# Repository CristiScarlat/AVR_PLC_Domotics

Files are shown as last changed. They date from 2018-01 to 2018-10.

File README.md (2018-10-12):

This is a programmable PLC for home automations build around ATmega32, 
the electronic schematic can be found in the HW folder and the firmware in the AP_FW.
The firmware was writen in C using Atmel_Studio.
This PLC is programmable using an interface made in Java, the java project can be found in AP_SW directory

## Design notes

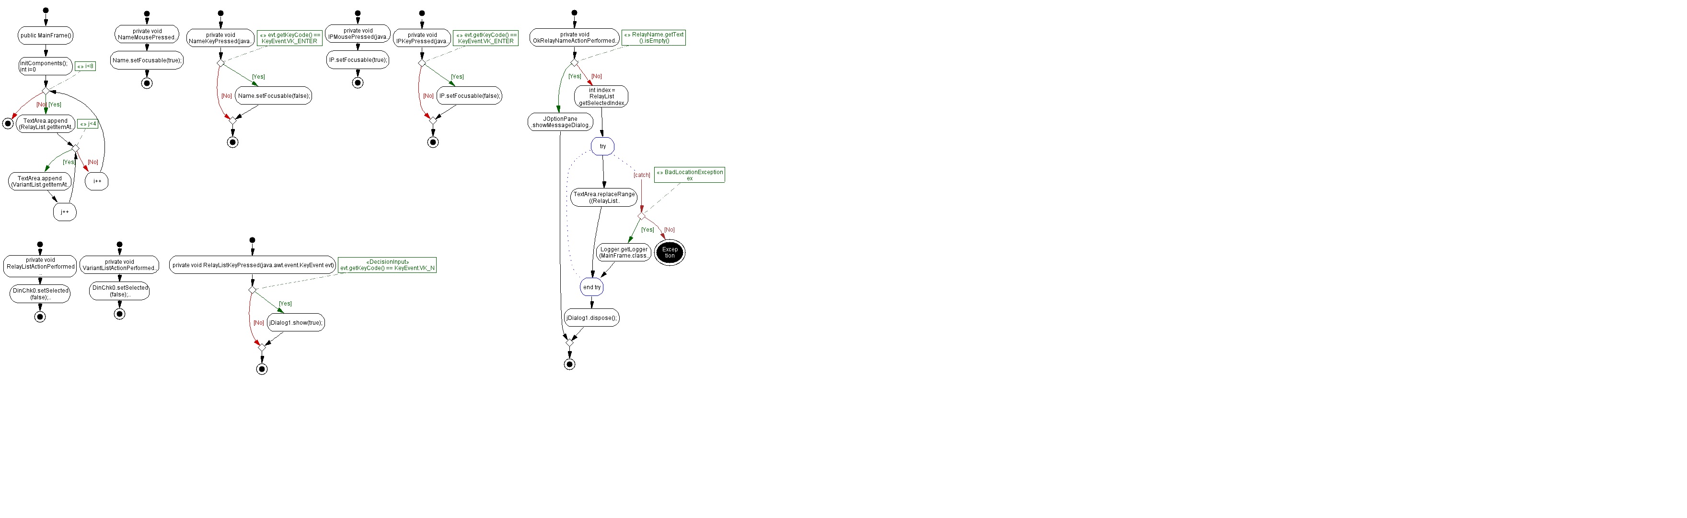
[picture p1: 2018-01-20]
AP_SW/UMLdiagrams.jpg

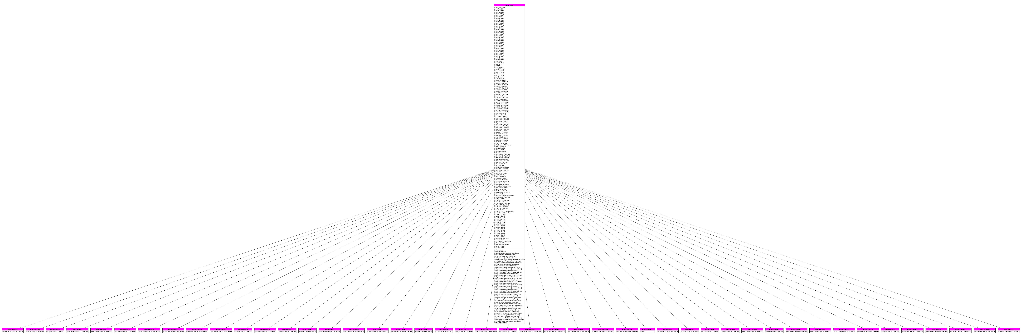
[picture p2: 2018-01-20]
AP_SW/UML.png

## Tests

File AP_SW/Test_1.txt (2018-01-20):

test/192.168.0.50/Digital IN 0/Digital IN 1/Digital IN 2/Digital IN 3/Digital IN 4/Digital IN 5/Digital IN 6/Digital IN 7/Analog IN 1 /Analog IN 2/Analog IN 3/Analog IN 4/Digital OUT 0/Digital OUT 1/Digital OUT 2/Digital OUT 3/Digital OUT 4/Digital OUT 5/Digital OUT 6/Digital OUT 7/r0d0v0r1d0v0r2a1214-408-v0r3a2408-622-v0r4a3615-816-v0r5a4816-1023-v0r6c13-13-08-10-v0r7l298-790-v0
Digital OUT 0:
Varianta 1:Digital IN 0->|
Varianta 2:-
Varianta 3:-
Varianta 4:-
Digital OUT 1:
Varianta 1:Digital IN 0->|
Varianta 2:-
Varianta 3:-
Varianta 4:-
Digital OUT 2:
Varianta 1:Analog IN 1 : ON = 1.0V<->2.0V->|
Varianta 2:-
Varianta 3:-
Varianta 4:-
Digital OUT 3:
Varianta 1:Analog IN 2: ON = 2.0V<->3.0V->|
Varianta 2:-
Varianta 3:-
Varianta 4:-
Digital OUT 4:
Varianta 1:Analog IN 3: ON = 3.0V<->4.0V->|
Varianta 2:-
Varianta 3:-
Varianta 4:-
Digital OUT 5:
Varianta 1:Analog IN 4: ON = 4.0V<->5.0V->|
Varianta 2:-
Varianta 3:-
Varianta 4:-
Digital OUT 6:
Varianta 1:Ceas: ON = 13:08 OFF = 13:10->|
Varianta 2:-
Varianta 3:-
Varianta 4:-
Digital OUT 7:
Varianta 1:Lumina: ON = 298 OFF = 790->|
Varianta 2:-
Varianta 3:-
Varianta 4:-

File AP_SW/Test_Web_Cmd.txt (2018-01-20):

Test_Web_Cmd/192.168.0.50/Digital IN 0/Digital IN 1/Digital IN 2/Digital IN 3/Digital IN 4/Digital IN 5/Digital IN 6/Digital IN 7/Analog IN 1/Analog IN 2/Analog IN 3/Analog IN 4/Digital OUT 0/Digital OUT 1/Digital OUT 2/Digital OUT 3/Digital OUT 4/Digital OUT 5/Digital OUT 6/Digital OUT 7/
Digital OUT 0:
Varianta 1:-
Varianta 2:-
Varianta 3:-
Varianta 4:-
Digital OUT 1:
Varianta 1:-
Varianta 2:-
Varianta 3:-
Varianta 4:-
Digital OUT 2:
Varianta 1:-
Varianta 2:-
Varianta 3:-
Varianta 4:-
Digital OUT 3:
Varianta 1:-
Varianta 2:-
Varianta 3:-
Varianta 4:-
Digital OUT 4:
Varianta 1:-
Varianta 2:-
Varianta 3:-
Varianta 4:-
Digital OUT 5:
Varianta 1:-
Varianta 2:-
Varianta 3:-
Varianta 4:-
Digital OUT 6:
Varianta 1:-
Varianta 2:-
Varianta 3:-
Varianta 4:-
Digital OUT 7:
Varianta 1:-
Varianta 2:-
Varianta 3:-
Varianta 4:-

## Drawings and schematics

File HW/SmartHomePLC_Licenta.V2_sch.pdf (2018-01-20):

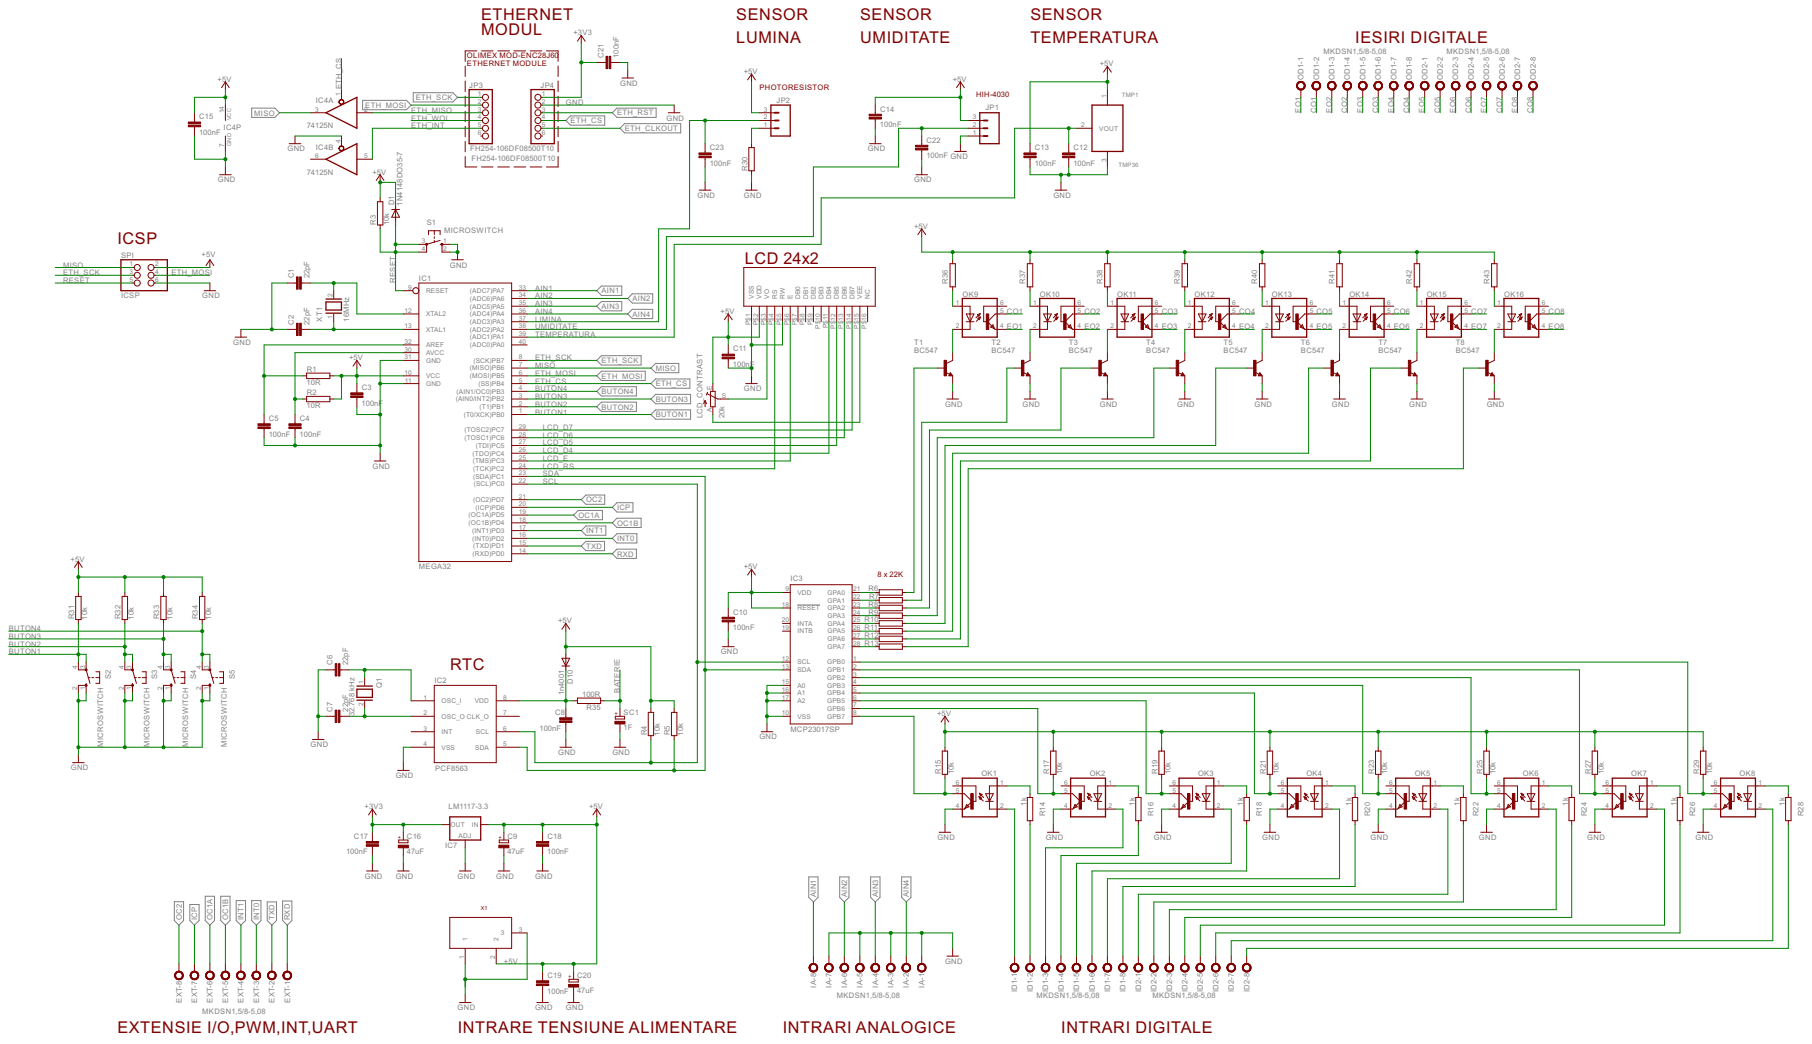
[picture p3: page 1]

PHOTORESISTOR OLIMEX MOD-ENC28J60 ETHERNET MODULE

28 LCD_D6
27 LCD_D5
26 LCD_D4
25 LCD_E

20 OC2 | ICP

MICROSWITCH MICROSWITCH

EXT-1 EXT-2 EXT-3 EXT-4 EXT-5 EXT-6 EXT-7 EXT-8

EXTENSIE I/O,PWM,INT,UART

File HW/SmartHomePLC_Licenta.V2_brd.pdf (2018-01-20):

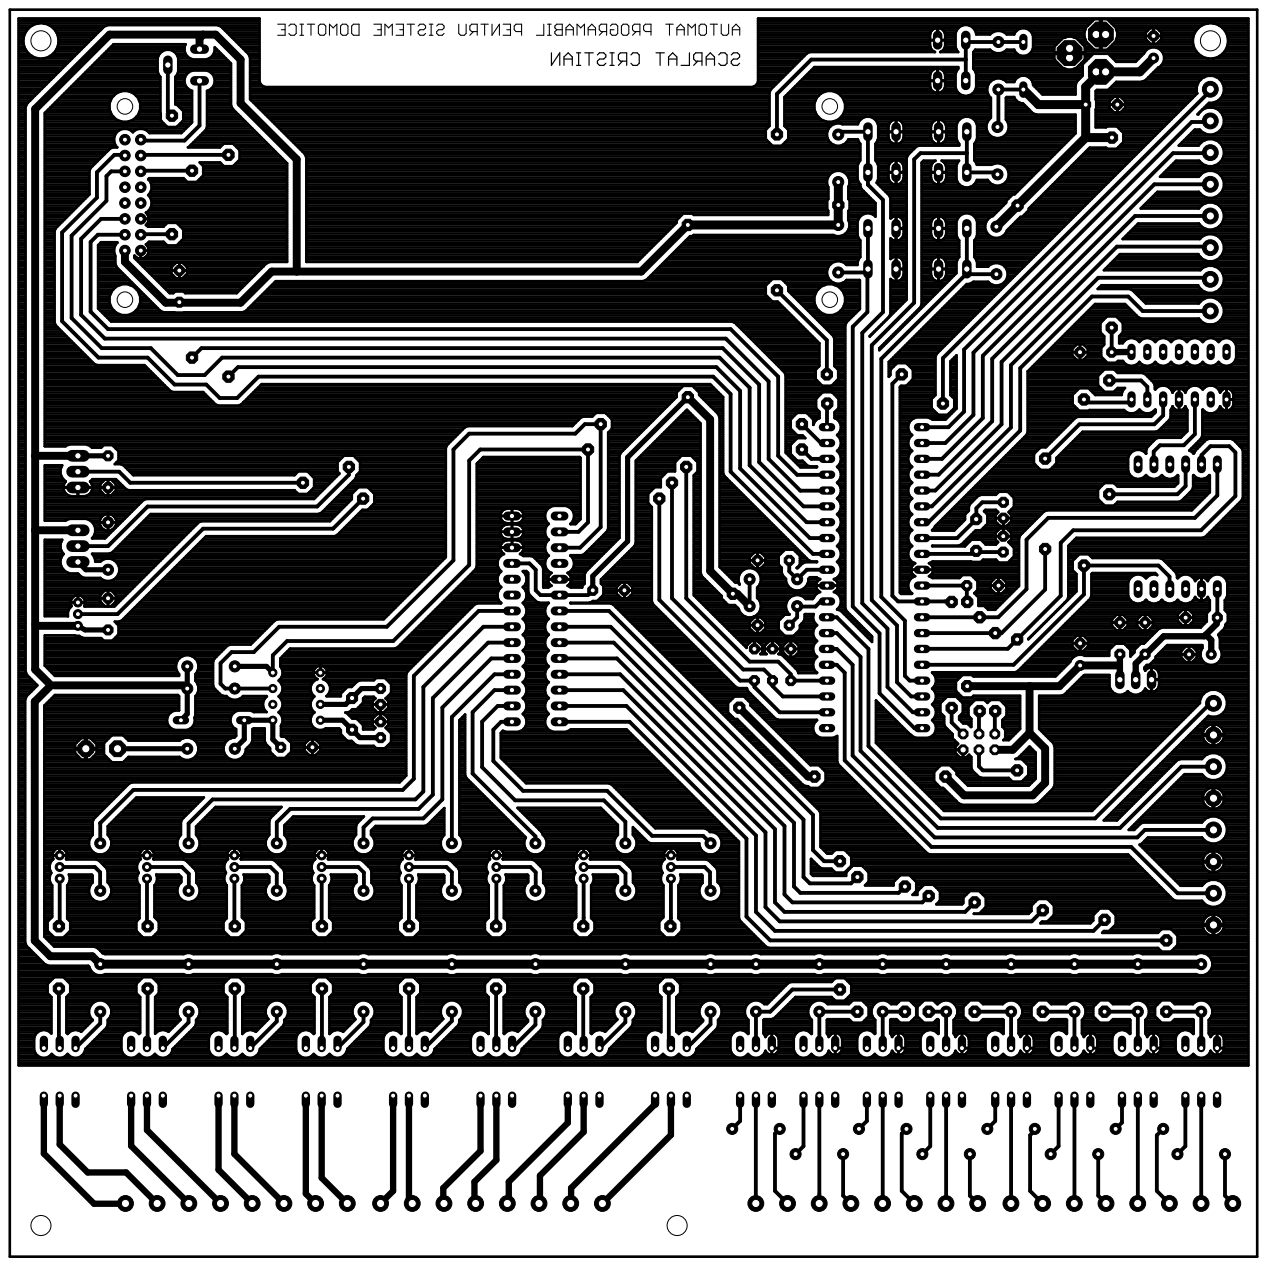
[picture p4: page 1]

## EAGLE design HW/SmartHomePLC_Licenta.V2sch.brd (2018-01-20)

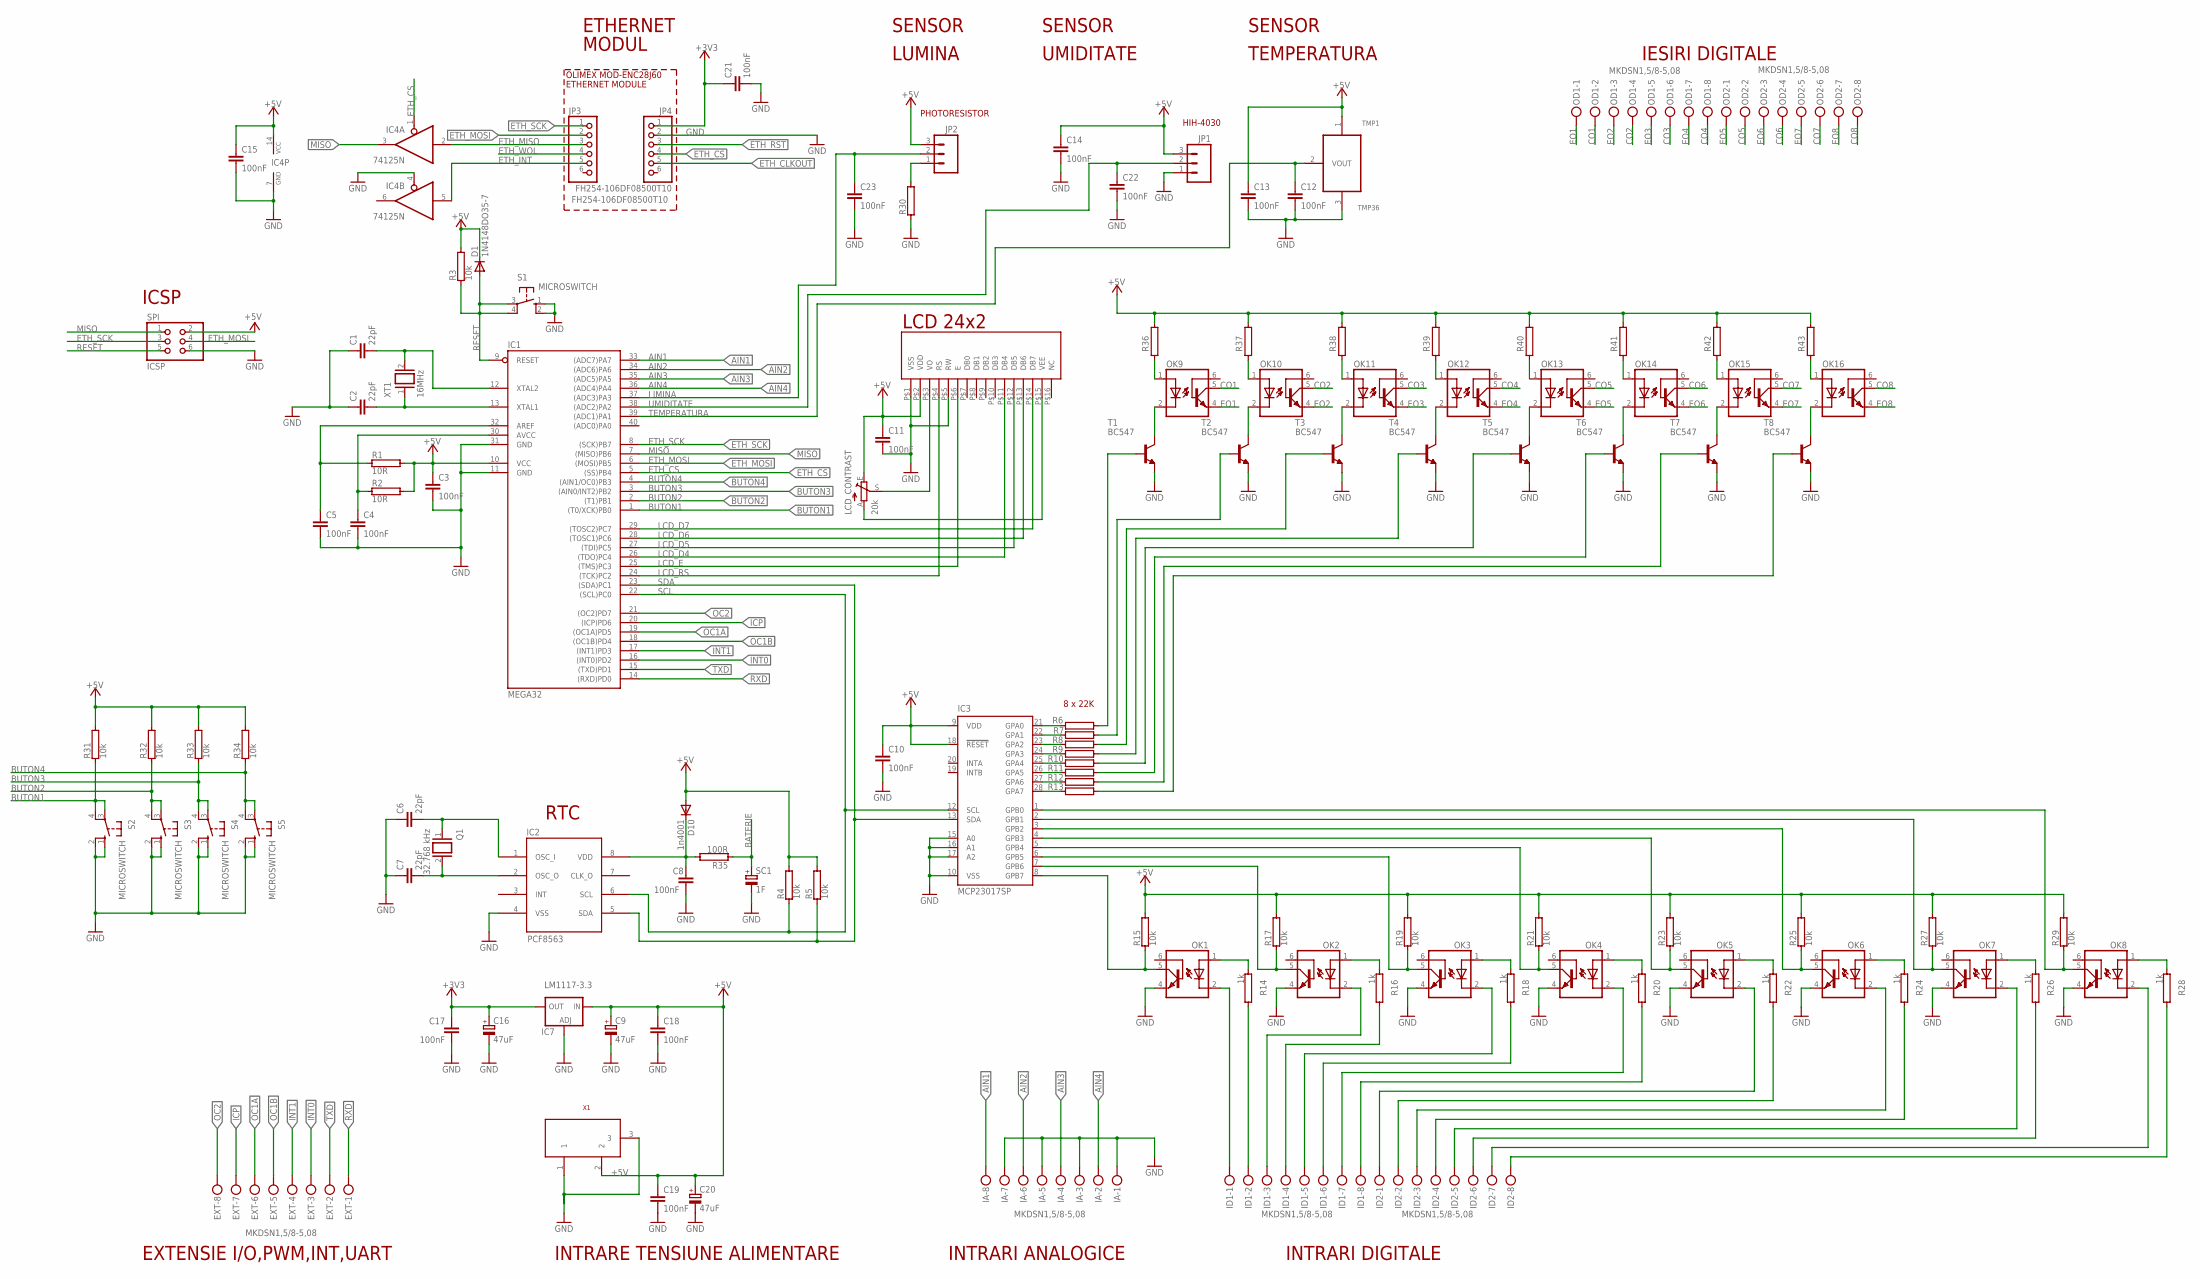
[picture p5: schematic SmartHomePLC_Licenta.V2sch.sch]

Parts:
C1, C2, C6, C7: 22pF; C2.5-2
C3, C4, C5, C8, C10, C11, C12, C13, C14, C15, C17, C18, C19, C21, C22, C23: 100nF; C5B2.5
C9, C16, C20: 47uF; E3,5-8
D1: 1N4148DO35-7; DO35-7
D10: 1n4001; DO35-10
EXT: MKDSN1,5/8-5,08
IA: MKDSN1,5/8-5,08
IC1: MEGA32; DIL40
IC2: PCF8563P; DIL08
IC3: MCP23017SP; DIL28-3
IC4: 74125N; DIL14
IC7: LM1117-3.3; 317TS
ID1, ID2: MKDSN1,5/8-5,08
JP1, JP2: M03LONGPADS; 1X03_LONGPADS
JP3, JP4: FH254-106DF08500T10; 1X06
LCD_CONTRAST: 20k; CA6V
OD1, OD2: MKDSN1,5/8-5,08
OK1, OK2, OK3, OK4, OK5, OK6, OK7, OK8, OK9, OK10, OK11, OK12, OK13, OK14, OK15, OK16: 4N35; DIL06
Q1: 32.768 kHz; QS
R1, R2: 10R; RS1/8
R3, R4, R5, R15, R17, R19, R21, R23, R25, R27, R29, R31, R32, R33, R34: 10k; RS1/8
R6, R7, R8, R9, R10, R11, R12, R13, R30, R36, R37, R38, R39, R40, R41, R42, R43: REZISTORSRS1/8; RS1/8
R14, R16, R18, R20, R22, R24, R26, R28: 1k; RS1/8
R35: 100R; RS1/8
S1, S2, S3, S4, S5: MICROSWITCH; B3F-10XX
SC1: 1F; DYNACAP-DB_1_3
SPI: ICSP; 2X03
T1, T2, T3, T4, T5, T6, T7, T8: BC547; BC-TO92
TMP1: TMP36; BC-TO92
U1: LCD_RC2402
X1: 0018_19746-POWER-SUPPLY; POWERSUPPLY_DC-21MM
XT1: 16MHz; QS

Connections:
+3V3: C16.+, C17.1, C21.1, IC7.2 (OUT), JP4.1
+5V: C3.1, C9.+, C10.1, C11.1, C13.1, C14.1, C15.1, C18.1, C19.1, C20.+, D1.C, D10.A, IC1.10 (VCC), IC3.9 (VDD), IC3.18 (!RESET), IC4.14 (VCC), IC7.3 (IN), JP1.3, JP2.3, LCD_CONTRAST.E, R1.2, R2.2, R3.2, R4.2, R5.2, R15.2, R17.2, R19.2, R21.2, R23.2, R25.2, R27.2, R29.2, R31.2, R32.2, R33.2, R34.2, R36.2, R37.2, R38.2, R39.2, R40.2, R41.2, R42.2, R43.2, SPI.2, TMP1.1 (+VS), U1.P$2 (VDD), X1.2
AIN1: IA.8, IC1.33 ((ADC7)PA7)
AIN2: IA.6, IC1.34 ((ADC6)PA6)
AIN3: IA.4, IC1.35 ((ADC5)PA5)
AIN4: IA.2, IC1.36 ((ADC4)PA4)
BATERIE: R35.1, SC1.+
BUTON1: IC1.1 ((T0/XCK)PB0), R31.1, S2.3, S2.4 (P1)
BUTON2: IC1.2 ((T1)PB1), R32.1, S3.3, S3.4 (P1)
BUTON3: IC1.3 ((AIN0/INT2)PB2), R33.1, S4.3, S4.4 (P1)
BUTON4: IC1.4 ((AIN1/OC0)PB3), R34.1, S5.3, S5.4 (P1)
CO1: OD1.2, OK9.5 (COL)
CO2: OD1.4, OK10.5 (COL)
CO3: OD1.6, OK11.5 (COL)
CO4: OD1.8, OK12.5 (COL)
CO5: OD2.2, OK13.5 (COL)
CO6: OD2.4, OK14.5 (COL)
CO7: OD2.6, OK15.5 (COL)
CO8: OD2.8, OK16.5 (COL)
EO1: OD1.1, OK9.4 (EMI)
EO2: OD1.3, OK10.4 (EMI)
EO3: OD1.5, OK11.4 (EMI)
EO4: OD1.7, OK12.4 (EMI)
EO5: OD2.1, OK13.4 (EMI)
EO6: OD2.3, OK14.4 (EMI)
EO7: OD2.5, OK15.4 (EMI)
EO8: OD2.7, OK16.4 (EMI)
ETH_CLKOUT: JP4.5
ETH_CS: IC1.5 ((SS)PB4), IC4.1 (OE), JP4.4
ETH_INT: IC4.5 (I), JP3.5
ETH_MISO: IC4.2 (I), JP3.3
ETH_MOSI: IC1.6 ((MOSI)PB5), JP3.2, SPI.4
ETH_RST: JP4.3
ETH_SCK: IC1.8 ((SCK)PB7), JP3.1, SPI.3
ETH_WOL: JP3.4
GND: C1.1, C2.1, C3.2, C4.2, C5.2, C6.1, C7.1, C8.2, C9.-, C10.2, C11.2, C12.2, C13.2, C14.2, C15.2, C16.-, C17.2, C18.2, C19.2, C20.-, C21.2, C22.2, C23.2, IA.1, IA.3, IA.5, IA.7, IC1.11 (GND), IC1.31 (GND), IC2.4 (VSS), IC3.10 (VSS), IC3.15 (A0), IC3.16 (A1), IC3.17 (A2), IC4.4 (OE), IC4.7 (GND), IC7.1 (ADJ), JP1.1, JP4.2, OK1.4 (EMI), OK2.4 (EMI), OK3.4 (EMI), OK4.4 (EMI), OK5.4 (EMI), OK6.4 (EMI), OK7.4 (EMI), OK8.4 (EMI), R30.1, S1.1 (S), S1.2 (S1), S2.1 (S), S2.2 (S1), S3.1 (S), S3.2 (S1), S4.1 (S), S4.2 (S1), S5.1 (S), S5.2 (S1), SC1.-, SPI.6, T1.1 (E), T2.1 (E), T3.1 (E), T4.1 (E), T5.1 (E), T6.1 (E), T7.1 (E), T8.1 (E), TMP1.3 (GND), U1.P$1 (VSS), U1.P$5 (RW), X1.1, X1.3
ICP: EXT.7, IC1.20 ((ICP)PD6)
INT0: EXT.3, IC1.16 ((INT0)PD2)
INT1: EXT.4, IC1.17 ((INT1)PD3)
LCD_D4: IC1.26 ((TDO)PC4), U1.P$11 (DB4)
LCD_D5: IC1.27 ((TDI)PC5), U1.P$12 (DB5)
LCD_D6: IC1.28 ((TOSC1)PC6), U1.P$13 (DB6)
LCD_D7: IC1.29 ((TOSC2)PC7), U1.P$14 (DB7)
LCD_E: IC1.25 ((TMS)PC3), U1.P$6 (E)
LCD_RS: IC1.24 ((TCK)PC2), U1.P$4 (RS)
LIMINA: C23.1, IC1.37 ((ADC3)PA3), JP2.2
MISO: IC1.7 ((MISO)PB6), IC4.3 (O), SPI.1
unnamed: C1.2, IC1.12 (XTAL2), XT1.2
unnamed: C2.2, IC1.13 (XTAL1), XT1.1
unnamed: C7.2, IC2.2 (OSC_O), Q1.2
unnamed: C4.1, IC1.30 (AVCC), R2.1
unnamed: C5.1, IC1.32 (AREF), R1.1
unnamed: IC3.28 (GPA7), R13.1
unnamed: IC3.27 (GPA6), R12.1
unnamed: IC3.26 (GPA5), R11.1
unnamed: IC3.25 (GPA4), R10.1
unnamed: IC3.24 (GPA3), R9.1
unnamed: C6.2, IC2.1 (OSC_I), Q1.1
unnamed: IC3.23 (GPA2), R8.1
unnamed: IC3.22 (GPA1), R7.1
unnamed: OK9.1 (A), R36.1
unnamed: IC3.21 (GPA0), R6.1
unnamed: OK9.2 (C), T1.3 (C)
unnamed: OK10.1 (A), R37.1
unnamed: R6.2, T1.2 (B)
unnamed: R7.2, T2.2 (B)
unnamed: OK11.1 (A), R38.1
unnamed: R8.2, T3.2 (B)
unnamed: R9.2, T4.2 (B)
unnamed: OK12.1 (A), R39.1
unnamed: OK13.1 (A), R40.1
unnamed: R10.2, T5.2 (B)
unnamed: LCD_CONTRAST.S, U1.P$3 (VO)
unnamed: LCD_CONTRAST.A, U1.P$15 (VEE)
unnamed: R11.2, T6.2 (B)
unnamed: OK14.1 (A), R41.1
unnamed: OK15.1 (A), R42.1
unnamed: R12.2, T7.2 (B)
unnamed: R13.2, T8.2 (B)
unnamed: OK1.1 (A), R14.1
unnamed: IC3.8 (GPB7), OK1.5 (COL), R15.1
unnamed: ID1.1, OK1.2 (C)
unnamed: OK16.1 (A), R43.1
unnamed: IC3.7 (GPB6), OK2.5 (COL), R17.1
unnamed: OK2.1 (A), R16.1
unnamed: ID1.3, OK2.2 (C)
unnamed: ID1.4, R16.2
unnamed: IC3.6 (GPB5), OK3.5 (COL), R19.1
unnamed: OK3.1 (A), R18.1
unnamed: ID1.5, OK3.2 (C)
unnamed: ID1.6, R18.2
unnamed: IC3.5 (GPB4), OK4.5 (COL), R21.1
unnamed: OK4.1 (A), R20.1
unnamed: ID1.7, OK4.2 (C)
unnamed: ID1.8, R20.2
unnamed: IC3.4 (GPB3), OK5.5 (COL), R23.1
unnamed: OK5.1 (A), R22.1
unnamed: ID2.1, OK5.2 (C)
unnamed: ID2.2, R22.2
unnamed: IC3.3 (GPB2), OK6.5 (COL), R25.1
unnamed: OK6.1 (A), R24.1
unnamed: ID2.3, OK6.2 (C)
unnamed: ID2.4, R24.2
unnamed: IC3.2 (GPB1), OK7.5 (COL), R27.1
unnamed: OK7.1 (A), R26.1
unnamed: OK10.2 (C), T2.3 (C)
unnamed: ID2.6, R26.2
unnamed: IC3.1 (GPB0), OK8.5 (COL), R29.1
unnamed: OK8.1 (A), R28.1
unnamed: ID2.7, OK8.2 (C)
unnamed: ID2.8, R28.2
unnamed: JP2.1, R30.2
unnamed: OK11.2 (C), T3.3 (C)
unnamed: OK12.2 (C), T4.3 (C)
unnamed: OK13.2 (C), T5.3 (C)
unnamed: OK14.2 (C), T6.3 (C)
unnamed: OK15.2 (C), T7.3 (C)
unnamed: OK16.2 (C), T8.3 (C)
unnamed: ID2.5, OK7.2 (C)
unnamed: C8.1, D10.C, IC2.8 (VDD), R35.2
unnamed: ID1.2, R14.2
OC1A: EXT.6, IC1.19 ((OC1A)PD5)
OC1B: EXT.5, IC1.18 ((OC1B)PD4)
OC2: EXT.8, IC1.21 ((OC2)PD7)
RESET: D1.A, IC1.9 (RESET), R3.1, S1.3, S1.4 (P1), SPI.5
RXD: EXT.1, IC1.14 ((RXD)PD0)
SCL: IC1.22 ((SCL)PC0), IC2.6 (SCL), IC3.12 (SCL), R4.1
SDA: IC1.23 ((SDA)PC1), IC2.5 (SDA), IC3.13 (SDA), R5.1
TEMPERATURA: C12.1, IC1.39 ((ADC1)PA1), TMP1.2 (VOUT)
TXD: EXT.2, IC1.15 ((TXD)PD1)
UMIDITATE: C22.1, IC1.38 ((ADC2)PA2), JP1.2

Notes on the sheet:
PHOTORESISTOR
OLIMEX MOD-ENC28J60
ETHERNET MODULE
INTRARI ANALOGICE
INTRARI DIGITALE
IESIRI DIGITALE
SENSOR
LUMINA
UMIDITATE
TEMPERATURA
ETHERNET
MODUL
RTC
ICSP
LCD 24x2
8 x 22K
INTRARE TENSIUNE ALIMENTARE
HIH-4030
EXTENSIE I/O,PWM,INT,UART

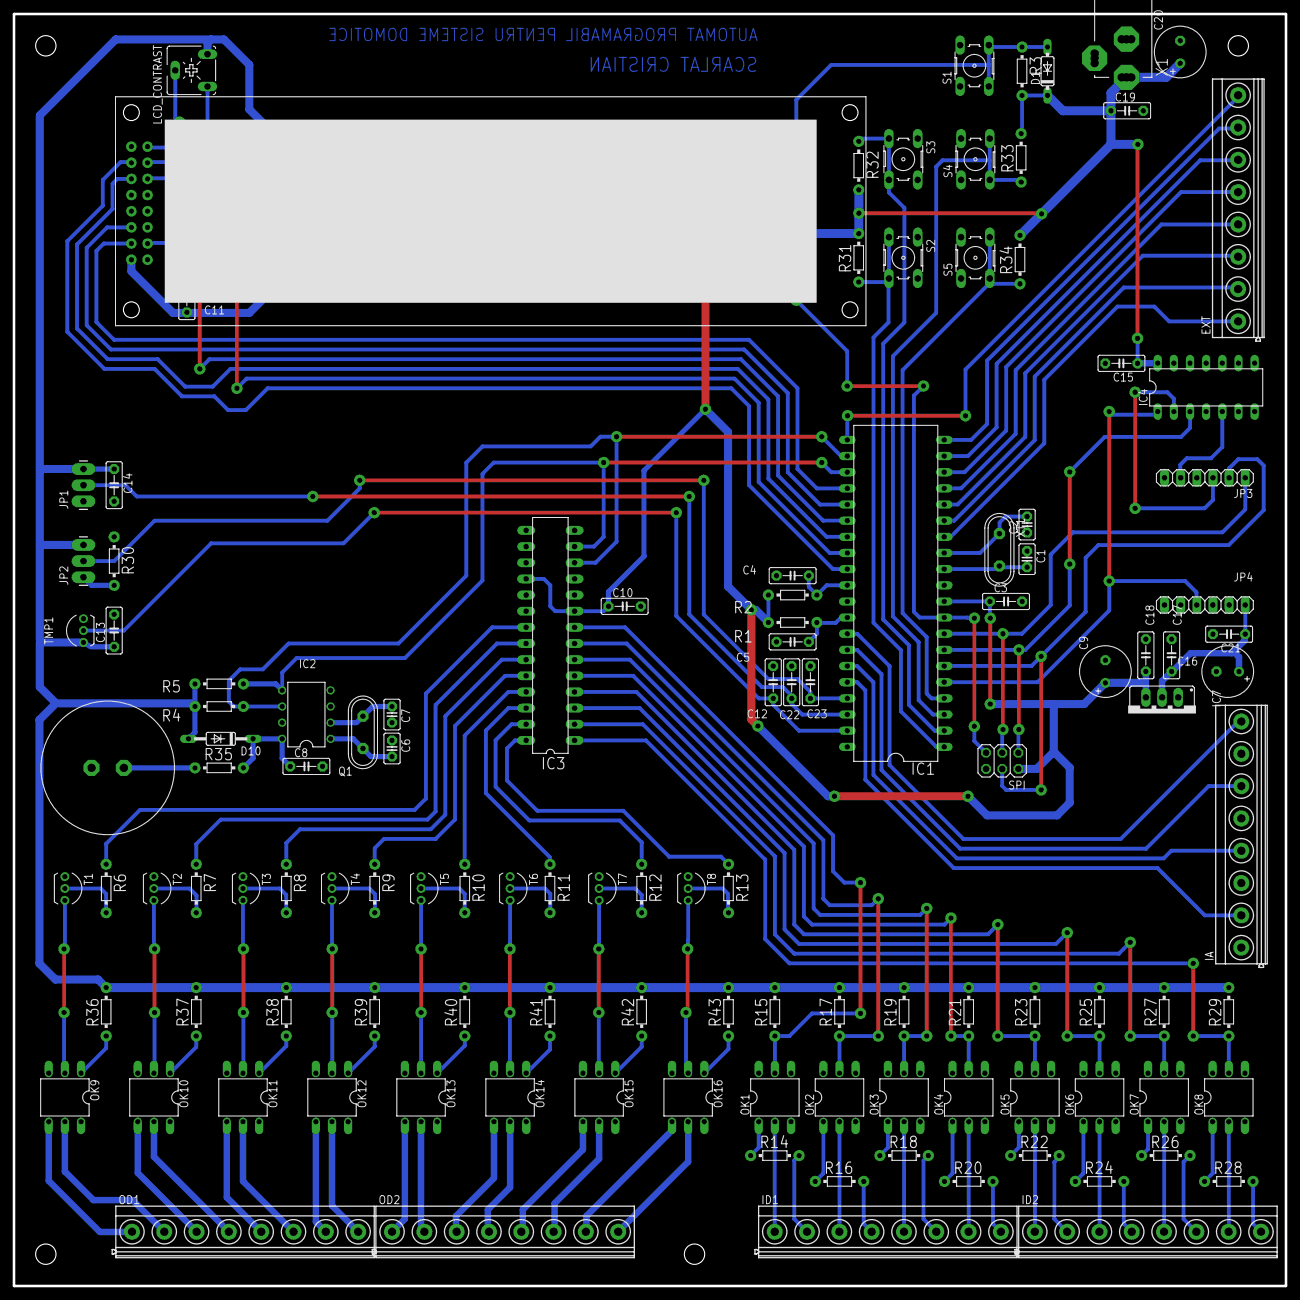
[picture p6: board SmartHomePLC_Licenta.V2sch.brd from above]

Board: 2 copper layers, 200.0 x 200.0 mm, 120 parts (0 on the bottom side), 128 nets.

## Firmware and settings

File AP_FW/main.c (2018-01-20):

/*
 * DomoticsPLC16.c
 *
 * Created: 9/30/2015 10:17:12 PM
 *  Author: Cristian Scarlat
 */ 
#define F_CPU 16000000UL

#include <stdio.h>
#include <stdlib.h>
#include <string.h>
#include <avr/io.h>
#include <avr/interrupt.h>
#include <avr/wdt.h>
#include <avr/eeprom.h>
#include <util/delay.h>

// ethernet interf
#include "ip_arp_udp.h"
//#include "ip_arp_udp.c"
#include "enc28j60.h"
//#include "enc28j60.c"
#include "net.h"
#include "timeout.h"
//#include "timeout.c"

#include "hd44780.h"
#include "hd44780_settings.h"
//#include "hd44780.c"

    char StrDisplay[10];
    char strRX[200];
	uint8_t DigIn = 0;//byte in care se citesc intrarile digitale de la MCP23017
	uint8_t ch = 0;// canal ADC
    float tempC;
	float hum;
	float light;
	uint8_t seconds;
	uint8_t minutes;
	uint8_t hours;
	uint8_t days;
	uint8_t weekdays = 0;
	uint8_t months;
	uint8_t years;
    uint8_t relays = 0x00;
	uint8_t menu = 0;
    uint8_t submenu = 0;
	//****************************************
	char Val[4];
	uint8_t relay=0;
	uint16_t valON=0;
	uint16_t valOFF =0;
	uint8_t Hon = 0;
	uint8_t Hoff = 0;
	uint8_t Mon = 0;
	uint8_t Moff = 0;
	uint8_t i=0;
	uint8_t j=0;
	uint8_t k=0;
	uint8_t eventsRX=0;//conditii gasite in strRX stringul receptionat de pe UDP
	uint8_t eventsTRUE = 0;// conditii TRUE , indeplinite pentru a comuta releul
	uint8_t OR = 0;
	uint8_t Validare[4];
	uint8_t flags;
	//***************************************
	
        // keep a track of number of overflows
        uint8_t refresh;
	
        uint16_t plen;
        uint8_t payloadlen=0;
	
// please modify the following two lines. mac and ip have to be unique
// in your local area network. You can not have the same numbers in
// two devices:
static uint8_t mymac[6] = {0x54,0x55,0x58,0x10,0x00,0x24};
static uint8_t myip[4] = {192,168,0,10};
static uint16_t myport =1200; // listen port for udp
// how did I get the mac addr? Translate the first 3 numbers into ascii is: TUX	
#define BUFFER_SIZE 250
static uint8_t buf[BUFFER_SIZE+1];
	

void TWI_Init()
{
	// 100kHz...SCL
	TWBR = 0x48;							//Set bitrate factor to 0
	TWSR &= ~((1<<TWPS1) | (1<<TWPS0));				//Set prescaler to 1
}

void TWI_Start()
{
	TWCR = (1<<TWINT) | (1<<TWEN) | (1<<TWSTA);
	while (!(TWCR & (1<<TWINT)));
}

void TWI_Stop()
{
	TWCR = (1<<TWINT) | (1<<TWEN) | (1<<TWSTO);
	while ((TWCR & (1<<TWSTO)));
}

uint8_t TWI_Read(uint8_t ack)
{
	TWCR = (1<<TWINT) | (1<<TWEN) | (((ack ? 1 : 0)<<TWEA));
	while (!(TWCR & (1<<TWINT)));
	return TWDR;
}


void TWI_Write(uint8_t byte)
{
	TWDR = byte;
	TWCR = (1<<TWINT) | (1<<TWEN);
	while (!(TWCR & (1<<TWINT)));
}
 

void init(void)
{
    DDRB &= ~((1 << 0)|(1 << 1)|(1 << 2)|(1 << 3));
////////////////////////Timer 0 and Interupt //////////////////////////////////////
   // set up timer with prescaler = 1024
    TCCR0 |= (1 << CS02)|(1 << CS00);
  //OCR set for 10ms
    OCR0 = 0x9B;
    // enable compare  interrupt
   TIMSK |= (1 << OCIE0);
    // enable global interrupts
    sei();
  
    // initialize overflow counter variable
    refresh = 0;
///////////////////////////////////////////////////////////////
	lcd_init();
	lcd_clrscr();
	lcd_puts("PLC FOR DOMOTICS");
	lcd_goto(0x40);
	lcd_puts("V1.0_10_2015");
	_delay_ms(1000);
	lcd_clrscr();
	lcd_puts("Author:");
	lcd_goto(0x40);
	lcd_puts("Cristian Scarlat");
	_delay_ms(1000);
        lcd_clrscr();
        _delay_ms(100);
	 TWI_Init();
         //PCF8563 Status and control registers write
	 TWI_Start();
         TWI_Write(0xA2);
	 TWI_Write(0x00);
	 TWI_Write(0x00);
         TWI_Stop();
         TWI_Start();
         TWI_Write(0xA2);
         TWI_Write(0x01);
	 TWI_Write(0x00);
	 TWI_Stop();
	 //MCP23017 init
         TWI_Start();
	 TWI_Write(0x40); //MCP23017 address A0=0,A1=0,A2=0 , Write mode
	 TWI_Write(0x00); //MCP23017 IODIRA register address
	 TWI_Write(0x00); //MCP23017 PORTA set to output
	 TWI_Stop();
	 TWI_Start();
	 TWI_Write(0x40); //MCP23017 address A0=0,A1=0,A2=0 , Write mode
	 TWI_Write(0x12); //MCP23017 GPIOA register address
	 TWI_Write(0x00); //MCP23017 reset port GPA
	 TWI_Stop();
	 TWI_Start();
	 TWI_Write(0x40); //MCP23017 address A0=0,A1=0,A2=0 , Write mode
	 TWI_Write(0x01); //MCP23017 IODIRB register address
	 TWI_Write(0xFF); //MCP23017 PORTB set to input
	 TWI_Stop();
	 //MCP23017 Read PortB*******************************************
	 TWI_Start();
	 TWI_Write(0x40); //MCP23017 address A0=0,A1=0,A2=0 , Write mode
	 TWI_Write(0x13); //MCP23017 GPIOB register address
	 TWI_Stop();
	 TWI_Start();
	 TWI_Write(0x41); //MCP23017 address A0=0,A1=0,A2=0 , Read mode
	 DigIn = TWI_Read(0);
	 TWI_Stop();
	 //***************************************************************
	 _delay_ms(100);
      //Analog inputs init
		//ADMUX = 1<<REFS0;
		ADMUX &= ~((1<<REFS0)|(1<<REFS1));//AREF,Internal Vreff turned off
		ADCSRA = (1<<ADEN)|(1<<ADPS2)|(1<<ADPS1)|(1<<ADPS0);
		//while(ADCSRA & (1<<ADSC));
        //*****************************************************************
	i=0;
	for(i=0;i<200;i++){
			strRX[i] = 0;
			}
	i=0;
	eeprom_read_block((char*)strRX,(void*)0,200);
	 /*initialize enc28j60*/
        enc28j60Init(mymac);
        delay_ms(20);

        
        /* Magjack leds configuration, see enc28j60 datasheet, page 11 */
        // LEDB=yellow LEDA=green
        //
        // 0x476 is PHLCON LEDA=links status, LEDB=receive/transmit
        // enc28j60PhyWrite(PHLCON,0b0000 0100 0111 01 10);
        enc28j60PhyWrite(PHLCON,0x476);
        delay_ms(20);

        //init the ethernet/ip layer:
        init_ip_arp_udp(mymac,myip);
}

void RelayToggle(uint8_t RelayNo)
{
	TWI_Start();
	TWI_Write(0x40); //MCP23017 address A0=0,A1=0,A2=0 , Write mode
	TWI_Write(0x12); //MCP23017 GPIOA register address
	relays ^= 1<<RelayNo;
	TWI_Write(relays); //MCP23017 set GPA0
	TWI_Stop();
}

void RelayON(uint8_t RelayNo)
{
	TWI_Start();
	TWI_Write(0x40); //MCP23017 address A0=0,A1=0,A2=0 , Write mode
	TWI_Write(0x12); //MCP23017 GPIOA register address
	relays |= (1<<RelayNo);
	TWI_Write(relays); //MCP23017 set GPA0
	TWI_Stop();
}

void RelayOFF(uint8_t RelayNo)
{
	TWI_Start();
	TWI_Write(0x40); //MCP23017 address A0=0,A1=0,A2=0 , Write mode
	TWI_Write(0x12); //MCP23017 GPIOA register address
	relays &= ~(1<<RelayNo);
	TWI_Write(relays); //MCP23017 set GPA0
	TWI_Stop();
}

void ReadDigIn(void)
{
	//MCP23017 Read PortB*******************************************
	 TWI_Start();
	 TWI_Write(0x40); //MCP23017 address A0=0,A1=0,A2=0 , Write mode
	 TWI_Write(0x13); //MCP23017 GPIOB register address
	 TWI_Stop();
	 TWI_Start();
	 TWI_Write(0x41); //MCP23017 address A0=0,A1=0,A2=0 , Read mode
	 DigIn = TWI_Read(0);
	 TWI_Stop();
	 //Revers order of bits******************************************
	 DigIn = (DigIn & 0xF0) >> 4 | (DigIn & 0x0F) << 4;
	 DigIn = (DigIn & 0xCC) >> 2 | (DigIn & 0x33) << 2;
	 DigIn = (DigIn & 0xAA) >> 1 | (DigIn & 0x55) << 1;
	 //***************************************************************
         DigIn = ~DigIn;//Operatie de NOT pentru ca iesirea optocuploarelor este cu colector in gol
}

void readtemp(void)
{               //set channel 1
	        ADMUX |= (1<<MUX0);
		ADMUX &= ~((1<<MUX1)|(1<<MUX2)|(1<<MUX3)|(1<<MUX4));
		// start single convertion
		// write ’1? to ADSC
		ADCSRA |= (1<<ADSC);
		// wait for conversion to complete
		// ADSC becomes ’0? again
		// till then, run loop continuously
		while(ADCSRA & (1<<ADSC));
		float Volt = (ADC*5)/1023.0;
		      tempC = (Volt-0.5)*100;
		dtostrf(tempC,5,1,StrDisplay);	
}

void readhum(void)
{        
          //set channel 2
	        ADMUX |= (1<<MUX1);
		ADMUX &= ~((1<<MUX0)|(1<<MUX2)|(1<<MUX3)|(1<<MUX4));
		// start single convertion
		// write ’1? to ADSC
		ADCSRA |= (1<<ADSC);
		// wait for conversion to complete
		// ADSC becomes ’0? again
		// till then, run loop continuously
		while(ADCSRA & (1<<ADSC));
		float Volt = (ADC*5.0)/1023.0;
		float  SensorRH = (Volt- 0.958) / 0.0307;
                 hum = SensorRH / (1.0546 - 0.00216 * tempC);
		dtostrf(hum,5,1,StrDisplay);	
}

uint16_t readlight()
{                //set channel 3
	        ADMUX |= (1<<MUX0)|(1<<MUX1);
		ADMUX &= ~((1<<MUX2)|(1<<MUX3)|(1<<MUX4));
		// start single convertion
		// write ’1? to ADSC
		ADCSRA |= (1<<ADSC);
		// wait for conversion to complete
		// ADSC becomes ’0? again
		// till then, run loop continuously
		while(ADCSRA & (1<<ADSC));
		light = ADC;
		return(light);
}
uint16_t readan (uint8_t ch)
{       ADMUX &= ~((1<<MUX0)|(1<<MUX1)|(1<<MUX2)|(1<<MUX3)|(1<<MUX4));
	switch(ch){
		case 1:
			ADMUX |= (1<<MUX0)|(1<<MUX1)|(1<<MUX2); 
			break;
		case 2:
			ADMUX |= (1<<MUX1)|(1<<MUX2); 
			break;
		case 3:
			ADMUX |= (1<<MUX0)|(1<<MUX2); 
			break;
		case 4:
			ADMUX |= 1<<MUX2; 
			break;
	}
	ADCSRA |= (1<<ADSC);
	while(ADCSRA & (1<<ADSC));
        uint16_t Val = ADC;
	return(Val);
}

// Converts a BCD (binary coded decimal) to decimal
uint8_t BcdToDec(uint8_t value)
{
  return ((value / 16) * 10 + value % 16);
}

// Converts a decimal to BCD (binary coded decimal)
uint8_t DecToBcd(uint8_t value){
  return ((value / 10) * 16 + value % 10);
}

void ReadRTC(void)
{
	 //Citire PCF8563 ********************************
	 TWI_Start();
	 TWI_Write(0xA2); //I2C Address pentru scriere
	 TWI_Write(0x02); //pointer la registru Seconds
	 TWI_Stop();
	 TWI_Start();
	 TWI_Write(0xA3); //I2C Address pentru citire *** adresele registrelor sunt incrementate automat (datasheet)
	 seconds = TWI_Read(1);//generate akc bit
	 minutes = TWI_Read(1);
	 hours = TWI_Read(1);
	 days = TWI_Read(1);
	 weekdays = TWI_Read(1);
	 months = TWI_Read(1);
	 years = TWI_Read(0); //do not generate akc bit
	 TWI_Stop();
	 //***********************************************
         seconds &= ~(1<<7);
         minutes &= ~(1<<7);
         hours &= ~((1<<7)|(1<<6));
         days &= ~((1<<7)|(1<<6));
         months &= ~((1<<7)|(1<<6)|(1<<5));
         seconds = BcdToDec(seconds);
         minutes = BcdToDec(minutes);
         hours = BcdToDec(hours);
         days = BcdToDec(days);
         months = BcdToDec(months);
         years = BcdToDec(years);
         
}
void WriteRTC(void)
{
 ////////////////convert Decimal values to BCD for PCF8563///////////////////
uint8_t setS = DecToBcd(seconds);
uint8_t setMin = DecToBcd(minutes);
uint8_t setH = DecToBcd(hours);
uint8_t setD = DecToBcd(days);
uint8_t setMon = DecToBcd(months);
uint8_t setY = DecToBcd(years);
////////////////////////////////////////////////////////////////////////////
	 TWI_Start();
	 TWI_Write(0xA2);//PCF8563 write I2C address
	 TWI_Write(0x02);// registru secunde, apoi valoarea registrilor este incrementata automat
	 TWI_Write(setS);
	 TWI_Write(setMin);
	 TWI_Write(setH);
	 TWI_Write(setD);
	 TWI_Write(weekdays);
	 TWI_Write(setMon);
	 TWI_Write(setY);
	 TWI_Stop();
}

void displayTime(){
                     lcd_clrscr();
            	     //lcd_goto(0);
                     if(hours < 10) lcd_puts("0");//afiseaza un "0" la zecimale daca ora<10
                     lcd_puts(itoa(hours,StrDisplay,10));// converteste integerul in sring si afiseaza pe LCD

                     lcd_puts(":");
                     if(minutes < 10)lcd_puts("0");
                     lcd_puts(itoa(minutes,StrDisplay,10));

                     //lcd_puts(":");
                     //if(seconds < 10)lcd_puts("0");
                     //lcd_puts(itoa(seconds,StrDisplay,10));

                     lcd_puts(" Date:");

                     if(days < 10)lcd_puts("0");
                     lcd_puts(itoa(days,StrDisplay,10));
                     lcd_puts("/");

                   //lcd_puts(itoa(weekdays,StrDisplay,10));
                   //StrDisplay[] = 0;
                   //lcd_puts("/");
                     if(months < 10)lcd_puts("0");	
                     lcd_puts(itoa(months,StrDisplay,10));

                     lcd_puts("/");
                     lcd_puts(itoa(years,StrDisplay,10));
}

void setTime(void){
        
        lcd_command(0x0E);//Cursor on blinking

 while(menu == 1){
        _delay_ms(100);
	displayTime();
	lcd_goto(0x40);//second line
	lcd_puts("IP:");
	lcd_goto(44);
	lcd_puts(itoa(myip[0],StrDisplay,10));
	lcd_puts(".");
	lcd_puts(itoa(myip[1],StrDisplay,10));
	lcd_puts(".");
	lcd_puts(itoa(myip[2],StrDisplay,10));
	lcd_puts(".");
	lcd_puts(itoa(myip[3],StrDisplay,10));
	lcd_goto(0);
	if(!(PINB & (1 << PINB1))){
		//init the ethernet/ip layer:
		init_ip_arp_udp(mymac,myip);
		lcd_command(0x0C);//Cursor off
		menu = 0;
		submenu = 0;
	}
	if(submenu == 0){
                 lcd_goto(0);
		if(!(PINB & (1 << PINB3))){
			_delay_ms(100);
			hours++;
			if(hours>23)hours=0;
		}
		if(!(PINB & (1 << PINB0))){
			_delay_ms(100);
			hours--;
			if(hours == 255)hours=23;
		}
		if(!(PINB & (1 << PINB2))){
                          while(!(PINB & (1 << PINB2)));
                         _delay_ms(100);
                        submenu++;				
                           }
	}
        if(submenu == 1){
                 lcd_goto(3);  
		if(!(PINB & (1 << PINB3))){
			_delay_ms(100);
			minutes++;
			if(minutes > 59)minutes=0;
		}
		if(!(PINB & (1 << PINB0))){
			_delay_ms(100);
			minutes--;
			if(minutes == 255)minutes=59;
		}
		if(!(PINB & (1 << PINB2))){
                          while(!(PINB & (1 << PINB2)));
                         _delay_ms(100);
                        submenu++;				
                           }
	}
        if(submenu == 2){
                 lcd_goto(11);
		if(!(PINB & (1 << PINB3))){
			_delay_ms(100);
			 days++;
			if(days > 31)days=0;				
		}
		if(!(PINB & (1 << PINB0))){
			_delay_ms(100);
			days--;
			if(days == 255)days=31;
		}
		if(!(PINB & (1 << PINB2))){
                          while(!(PINB & (1 << PINB2)));
                         _delay_ms(100);
                        submenu++;
                           }
	}
	if(submenu == 3){
                 lcd_goto(14);
		if(!(PINB & (1 << PINB3))){
			_delay_ms(100);
			 months++;
			if(months > 12)months=0;
		}
		if(!(PINB & (1 << PINB0))){
			_delay_ms(100);
			months--;
			if(months == 255)months=12;
		}
		if(!(PINB & (1 << PINB2))){
                          while(!(PINB & (1 << PINB2)));
                         _delay_ms(100);
                        submenu++;				
                           }
	}
	if(submenu == 4){
                 lcd_goto(17);
		if(!(PINB & (1 << PINB3))){
			_delay_ms(100);
			 years++;
			if(years > 99)years=0;
		}
		if(!(PINB & (1 << PINB0))){
			_delay_ms(100);
			years--;
			if(years == 255)years=99;
		}
		if(!(PINB & (1 << PINB2))){
                          while(!(PINB & (1 << PINB2)));
                         _delay_ms(100);
                        submenu++;				
                           }
	}
	if(submenu == 5){

			  //uint8_t myip[4] = {192,168,0,10};
				lcd_goto(45); 
				lcd_command(0x0E);//Cursor on blinking 		
			  if(!(PINB & (1 << PINB3))){
				  _delay_ms(100);
				  myip[0]++;

			  }
			  if(!(PINB & (1 << PINB0))){
				  _delay_ms(100);
				  myip[0]--;

			  }
			  if(!(PINB & (1 << PINB2))){
				  while(!(PINB & (1 << PINB2)));
				  _delay_ms(100);
				  submenu++;
			  }
	}
	if(submenu == 6){

			//uint8_t myip[4] = {192,168,0,10};
			lcd_goto(0x49);//second line

			if(!(PINB & (1 << PINB3))){
				_delay_ms(100);
				myip[1]++;

			}
			if(!(PINB & (1 << PINB0))){
				_delay_ms(100);
				myip[1]--;

			}
			if(!(PINB & (1 << PINB2))){
				while(!(PINB & (1 << PINB2)));
				_delay_ms(100);
				submenu++;
			}
		}
	if(submenu == 7){

				//uint8_t myip[4] = {192,168,0,10};
				lcd_goto(0x4C);//second line

				if(!(PINB & (1 << PINB3))){
					_delay_ms(100);
					myip[2]++;

				}
				if(!(PINB & (1 << PINB0))){
					_delay_ms(100);
					myip[2]--;

				}
				if(!(PINB & (1 << PINB2))){
					while(!(PINB & (1 << PINB2)));
					_delay_ms(100);
					submenu++;
				}
			}
	if(submenu == 8){

					//uint8_t myip[4] = {192,168,0,10};
					lcd_goto(0x50);//second line

					if(!(PINB & (1 << PINB3))){
						_delay_ms(100);
						myip[3]++;

					}
					if(!(PINB & (1 << PINB0))){
						_delay_ms(100);
						myip[3]--;

					}
					if(!(PINB & (1 << PINB2))){
						while(!(PINB & (1 << PINB2)));
						_delay_ms(100);
						submenu++;
					}
				}
		if(submenu == 9){
						 WriteRTC();
						 lcd_command(0x0C);//Cursor off
						 lcd_clrscr();
						 menu = 0;
						submenu = 0;
		}
  }
}
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
int main()
{    
	init();
	while(1)
	{
		if(menu == 1) setTime();
	
		if(menu == 0)
			{

					if(refresh>=50 && !((flags >> 0) & 1)){
						 refresh = 0;
						ReadRTC();
						displayTime(); 
						lcd_goto(0x40);
						lcd_puts("Temp:");
						readtemp();
						//dtostrf(readan(2),5,1,StrDisplay);
						lcd_puts(StrDisplay);
						lcd_puts("C ");
						lcd_puts("Hum:");
						readhum();
						lcd_puts(StrDisplay);
						lcd_puts("% "); 
						readlight();                           
						 } 
					if(refresh>=30 && (flags >> 0) & 1){
						refresh = 0;
						lcd_clrscr();
						float Volt = (readan(1)*5.0)/1023.0;
						dtostrf(Volt,3,1,StrDisplay);
						lcd_puts("A1:");
						lcd_puts(StrDisplay);
						lcd_puts("V");
						Volt = (readan(2)*5.0)/1023.0;
						dtostrf(Volt,3,1,StrDisplay);
						lcd_puts(" A2:");
						lcd_puts(StrDisplay);
						lcd_puts("V");
						Volt = (readan(3)*5.0)/1023.0;
						dtostrf(Volt,3,1,StrDisplay);
						lcd_puts(" A3:");
						lcd_puts(StrDisplay);
						lcd_puts("V");
						Volt = (readan(4)*5.0)/1023.0;
						dtostrf(Volt,3,1,StrDisplay);
						lcd_goto(0x40);
						lcd_puts("A4:");
						lcd_puts(StrDisplay);
						lcd_puts("V");
						int light = itoa(readlight(),StrDisplay,10);
						lcd_puts("  Lumina: ");
						lcd_puts(light);
						}
					
			if(!(PINB & (1 << PINB2)))
				{
                                 _delay_ms(100);
                                menu = 1;				
				}
			if(!(PINB & (1 << PINB1)))
				{
                                 _delay_ms(100);
                                menu = 0;				
				}
			if(!(PINB & (1 << PINB3)))
				{
					flags |= 1<<0;
					_delay_ms(100);
				}
			if(!(PINB & (1 << PINB1)))
			{
				flags &= ~(1<<0);
				_delay_ms(100);
			}
					   
		EventCheck();
	}
	   // get the next new packet:
                plen = enc28j60PacketReceive(BUFFER_SIZE, buf);

                /*plen will ne unequal to zero if there is a valid 
                 * packet (without crc error) */
                if(plen==0)
			{
				continue;
			}
                // arp is broadcast if unknown but a host may also
                // verify the mac address by sending it to 
                // a unicast address.
                if(eth_type_is_arp_and_my_ip(buf,plen))
			{
				make_arp_answer_from_request(buf,plen);
				continue;
			}
                // check if ip packets (icmp or udp) are for us:
                if(eth_type_is_ip_and_my_ip(buf,plen)==0)
			{
				continue;
			}
                

                        
                if(buf[IP_PROTO_P]==IP_PROTO_ICMP_V && buf[ICMP_TYPE_P]==ICMP_TYPE_ECHOREQUEST_V)
			{
				// a ping packet, let's send pong
				make_echo_reply_from_request(buf,plen);
				continue;
			}
                if (buf[IP_PROTO_P]==IP_PROTO_UDP_V)
			{
				// payloadlen=buf[UDP_LEN_L_P]-UDP_HEADER_LEN;
				// you must sent a string starting with v
				// e.g udpcom version 10.0.0.24
				for(int i=0;i<200;i++)
					{
						strRX[i] = 0;
					}
	//Decodificare mesaj rx UDP and write to EEPROM*****************************************************
				strcpy(strRX,(char*)&buf[UDP_DATA_P]);// copie in str mesajul string primit pe UDP
				if(strncmp("conf",strRX,4)==0)// daca primul din mesaj este 'conf', atunci copiaza stringul in eeprom si in functia Eventcheck incepe decodificarea
					{
						strcpy(strRX,(char*)&strRX[4]);//'conf' este eliminat
						eeprom_update_block(&strRX,(void*)0,200);
					}
				if(strncmp("cmd",strRX,3)==0)
					{
						strcpy(strRX,(char*)&strRX[3]);//'cmd' este eliminat
							switch(strRX[0]){	
								case '0' :
									RelayToggle(0);
									break;	
								case '1' :
									RelayToggle(1);
									break;
								case '2' :
									RelayToggle(2);
									break;
								case '3' :
									RelayToggle(3);
									break;
								case '4' :
									RelayToggle(4);
									break;
								case '5' :
									RelayToggle(5);
									break;
								case '6' :
									RelayToggle(6);
									break;
								case '7' :
									RelayToggle(7);
									break;
								}
							
						for(i=0;i<200;i++)
							{
								strRX[i] = 0;
							}
						i=0;
						eeprom_read_block((char*)strRX,(void*)0,200);			
					}
			}	
	//******************************************************************************		
			
                        	make_udp_reply_from_request(buf,strRX,strnlen(strRX,200),myport);
				
	}
}

ISR(TIMER0_COMP_vect)
{
	TCNT0 = 0;
	refresh++;

}

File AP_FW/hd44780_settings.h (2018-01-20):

#ifndef HD44780_SETTINGS_H
#define HD44780_SETTINGS_H

#define F_CPU                    16000000     // Set Clock Frequency

#define USE_ADELAY_LIBRARY       0           // Set to 1 to use my ADELAY library, 0 to use internal delay functions
#define LCD_BITS                 4           // 4 for 4 Bit I/O Mode, 8 for 8 Bit I/O Mode
#define RW_LINE_IMPLEMENTED      0           // 0 for no RW line (RW on LCD tied to ground), 1 for RW line present
#define WAIT_MODE                0           // 0=Use Delay Method (Faster if running <10Mhz)
                                             // 1=Use Check Busy Flag (Faster if running >10Mhz) ***Requires RW Line***
#define DELAY_RESET              15          // in mS

#if (LCD_BITS==8)                            // If using 8 bit mode, you must configure DB0-DB7
  #define LCD_DB0_PORT           PORTC
  #define LCD_DB0_PIN            0
  #define LCD_DB1_PORT           PORTC
  #define LCD_DB1_PIN            1
  #define LCD_DB2_PORT           PORTC
  #define LCD_DB2_PIN            2
  #define LCD_DB3_PORT           PORTC
  #define LCD_DB3_PIN            3
#endif
#define LCD_DB4_PORT             PORTC       // If using 4 bit omde, you must configure DB4-DB7
#define LCD_DB4_PIN              4
#define LCD_DB5_PORT             PORTC
#define LCD_DB5_PIN              5
#define LCD_DB6_PORT             PORTC
#define LCD_DB6_PIN              6
#define LCD_DB7_PORT             PORTC
#define LCD_DB7_PIN              7

#define LCD_RS_PORT              PORTC       // Port for RS line
#define LCD_RS_PIN               2           // Pin for RS line

#define LCD_RW_PORT              PORTC       // Port for RW line (ONLY used if RW_LINE_IMPLEMENTED=1)
#define LCD_RW_PIN               6           // Pin for RW line (ONLY used if RW_LINE_IMPLEMENTED=1)

#define LCD_DISPLAYS             1           // Up to 4 LCD displays can be used at one time
                                             // All pins are shared between displays except for the E
                                             // pin which each display will have its own

                                             // Display 1 Settings - if you only have 1 display, YOU MUST SET THESE
#define LCD_DISPLAY_LINES        2           // Number of Lines, Only Used for Set I/O Mode Command
#define LCD_E_PORT               PORTC       // Port for E line
#define LCD_E_PIN                3           // Pin for E line

#if (LCD_DISPLAYS>=2)                        // If you have 2 displays, set these and change LCD_DISPLAYS=2
  #define LCD_DISPLAY2_LINES     2           // Number of Lines, Only Used for Set I/O Mode Command
  #define LCD_E2_PORT            PORTC       // Port for E line
  #define LCD_E2_PIN             5           // Pin for E line
#endif

#if (LCD_DISPLAYS>=3)                        // If you have 3 displays, set these and change LCD_DISPLAYS=3
  #define LCD_DISPLAY3_LINES     2           // Number of Lines, Only Used for Set I/O Mode Command
  #define LCD_E3_PORT            PORTC       // Port for E line
  #define LCD_E3_PIN             5           // Pin for E line
#endif

#if (LCD_DISPLAYS>=4)                        // If you have 4 displays, set these and change LCD_DISPLAYS=4
  #define LCD_DISPLAY4_LINES     2           // Number of Lines, Only Used for Set I/O Mode Command
  #define LCD_E4_PORT            PORTC       // Port for E line
  #define LCD_E4_PIN             5           // Pin for E line
#endif

#endif
